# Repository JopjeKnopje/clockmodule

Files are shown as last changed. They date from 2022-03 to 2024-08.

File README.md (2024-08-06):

# Clock Module

The idea behind this project is to have a standalone clock circuit to debug ICs at a very low clock speed.

It is mainly inspired by [Ben Eater's](https://eater.net/8bit/clock) version.

### Features
- Manual pulse Mode.
- Variable frequency clock.
- DC Input Jack 7v - 15v @ approx. 100mA.
- Raw 5v power in for breadboard compatability.
- Lots of LEDs :)

### Parts
- 2x 0.01uF - Ceramic Capacitor
- 2x 4.7uF - Capacitor
- 1x 470uF - Capacitor
- 1x .33uF - Ceramic Capacitor
- 4x .1uF - Ceramic Capacitor
- 1x 1uF - Capacitor
- 1x 1N4007 - Diode
- 4x 5mm LED
- 2x 01x02 Female Pin header
- 1x DC Jack
- 6x 1K - Resistor
- 2x 51K - Resistor
- 2x 10K - Resistor
- 1x 100K - Potentiometer linear
- 2x Button
- 3x NE555P
- 1x L7805
- 1x 7400

### What does it look like
#### KiCad Render
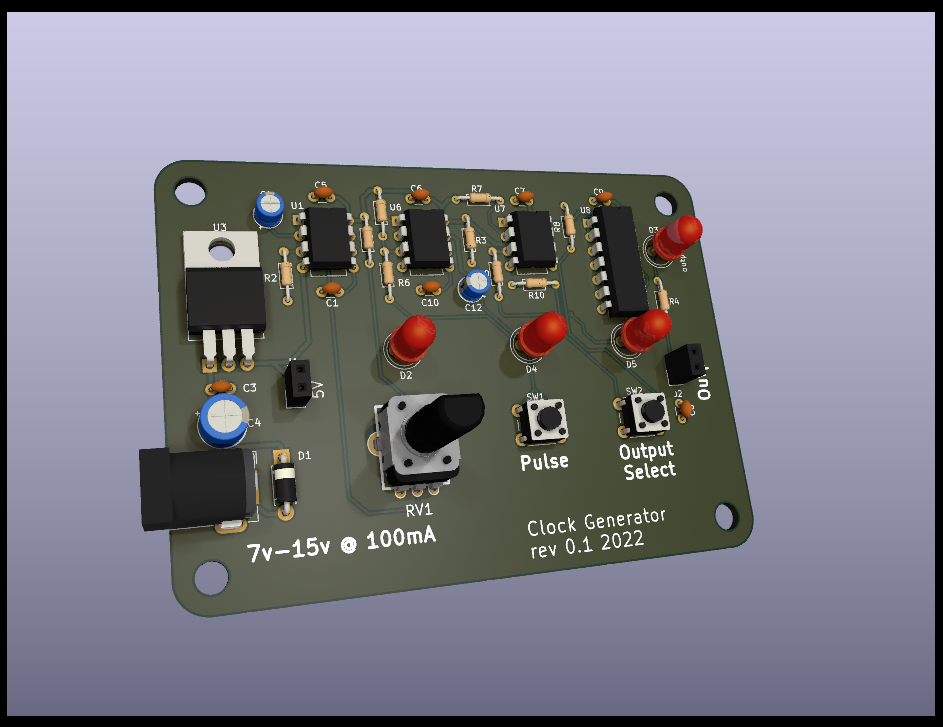
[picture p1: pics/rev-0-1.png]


### Todo
- [ ] Use CMOS ICs for a 5vpp output
- [x] Add partslist
- [ ] Add photos
- [x] Swap silkscreen position of c3 and c4 
- [x] Different footprint for c8

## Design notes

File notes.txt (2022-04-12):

https://www.falstad.com/circuit/circuitjs.html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

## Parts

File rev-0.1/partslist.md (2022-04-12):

- 2x 0.01uF, C
- 2x 4.7uF, C_Polarized
- 1x 470, C_Polarized
- 1x .33uF, C
- 4x .1uF, C
- 1x 1uF, C_Polarized
- 1x 1N4007, D
- 4x LED, LED
- 4x MountingHole, MountingHole
- 1x Vin, Conn_01x02_Female
- 1x Clock output, Conn_01x02_Female
- 1x DC Input, Barrel_Jack_Switch
- 6x 1K, R
- 2x 51K, R
- 2x 10K, R
- 1x 100K, R_Potentiometer
- 2x SW_Push, SW_Push
- 3x NE555P, NE555P
- 1x L7805_J, L7805_J
- 1x 7400, 7400

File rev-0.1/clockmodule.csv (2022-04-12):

Item | Qty | Reference(s) | Value | LibPart | Footprint | Datasheet
 |  | C1 | 0.01uF | Device:C | Capacitor_THT:C_Disc_D3.0mm_W1.6mm_P2.50mm | ~
 |  | C2 | 4.7uF | Device:C_Polarized | Capacitor_THT:CP_Radial_D4.0mm_P1.50mm | ~
 |  | C3 | 470 | Device:C_Polarized | Capacitor_THT:CP_Radial_D6.3mm_P2.50mm | ~
 |  | C4 | .33uF | Device:C | Capacitor_THT:C_Disc_D3.0mm_W1.6mm_P2.50mm | ~
 |  | C5 | .1uF | Device:C | Capacitor_THT:C_Disc_D3.0mm_W1.6mm_P2.50mm | ~
 |  | C6 | .1uF | Device:C | Capacitor_THT:C_Disc_D3.0mm_W1.6mm_P2.50mm | ~
 |  | C7 | .1uF | Device:C | Capacitor_THT:C_Disc_D3.0mm_W1.6mm_P2.50mm | ~
 |  | C8 | 1uF | Device:C_Polarized | Capacitor_THT:C_Disc_D3.0mm_W1.6mm_P2.50mm | ~
 |  | C9 | .1uF | Device:C | Capacitor_THT:C_Disc_D3.0mm_W1.6mm_P2.50mm | ~
 |  | C10 | 0.01uF | Device:C | Capacitor_THT:C_Disc_D3.0mm_W1.6mm_P2.50mm | ~
 |  | C12 | 4.7uF | Device:C_Polarized | Capacitor_THT:CP_Radial_D4.0mm_P1.50mm | ~
 |  | D1 | 1N4007 | Device:D | Diode_THT:D_DO-41_SOD81_P7.62mm_Horizontal | ~
 |  | D2 | LED | Device:LED | LED_THT:LED_D5.0mm | ~
 |  | D3 | LED | Device:LED | LED_THT:LED_D5.0mm | ~
 |  | D4 | LED | Device:LED | LED_THT:LED_D5.0mm | ~
 |  | D5 | LED | Device:LED | LED_THT:LED_D5.0mm | ~
 |  | H1 | MountingHole | Mechanical:MountingHole | MountingHole:MountingHole_4.3mm_M4 | ~
 |  | H2 | MountingHole | Mechanical:MountingHole | MountingHole:MountingHole_4.3mm_M4 | ~
 |  | H3 | MountingHole | Mechanical:MountingHole | MountingHole:MountingHole_4.3mm_M4 | ~
 |  | H4 | MountingHole | Mechanical:MountingHole | MountingHole:MountingHole_4.3mm_M4 | ~
 |  | J1 | Vin | Connector:Conn_01x02_Female | Connector_PinSocket_2.54mm:PinSocket_1x02_P2.54mm_Vertical | ~
 |  | J2 | Clock output | Connector:Conn_01x02_Female | Connector_PinSocket_2.54mm:PinSocket_1x02_P2.54mm_Vertical | ~
 |  | J3 | DC Input | Connector:Barrel_Jack_Switch | Connector_BarrelJack:BarrelJack_GCT_DCJ200-10-A_Horizontal | ~
 |  | R1 | 1K | Device:R | Resistor_THT:R_Axial_DIN0204_L3.6mm_D1.6mm_P7.62mm_Horizontal | ~
 |  | R2 | 1K | Device:R | Resistor_THT:R_Axial_DIN0204_L3.6mm_D1.6mm_P7.62mm_Horizontal | ~
 |  | R3 | 1K | Device:R | Resistor_THT:R_Axial_DIN0204_L3.6mm_D1.6mm_P7.62mm_Horizontal | ~
 |  | R4 | 1K | Device:R | Resistor_THT:R_Axial_DIN0204_L3.6mm_D1.6mm_P7.62mm_Horizontal | ~
 |  | R5 | 51K | Device:R | Resistor_THT:R_Axial_DIN0204_L3.6mm_D1.6mm_P7.62mm_Horizontal | ~
 |  | R6 | 1K | Device:R | Resistor_THT:R_Axial_DIN0204_L3.6mm_D1.6mm_P7.62mm_Horizontal | ~
 |  | R7 | 10K | Device:R | Resistor_THT:R_Axial_DIN0204_L3.6mm_D1.6mm_P7.62mm_Horizontal | ~
 |  | R8 | 10K | Device:R | Resistor_THT:R_Axial_DIN0204_L3.6mm_D1.6mm_P7.62mm_Horizontal | ~
 |  | R9 | 1K | Device:R | Resistor_THT:R_Axial_DIN0204_L3.6mm_D1.6mm_P7.62mm_Horizontal | ~
 |  | R10 | 51K | Device:R | Resistor_THT:R_Axial_DIN0204_L3.6mm_D1.6mm_P7.62mm_Horizontal | ~
 |  | RV1 | 100K | Device:R_Potentiometer | w_pth_resistors:trimmer_alps-rk09k1130ah1 | ~
 |  | SW1 | SW_Push | Switch:SW_Push | Button_Switch_THT:SW_PUSH_6mm_H5mm | ~
 |  | SW2 | SW_Push | Switch:SW_Push | Button_Switch_THT:SW_PUSH_6mm_H5mm | ~
 |  | U1 | NE555P | Timer:NE555P | Package_DIP:DIP-8_W7.62mm | http://www.ti.com/lit/ds/symlink/ne555.pdf
 |  | U3 | L7805_J | joppe:L7805_J | Package_TO_SOT_THT:TO-220-3_Horizontal_TabDown | http://www.st.com/content/ccc/resource/technical/document/datasheet/41/4f/b3/b0/12/d4/47/88/CD00000444.pdf/files/CD00000444.pdf/jcr:content/translations/en.CD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
 |  | U6 | NE555P | Timer:NE555P | Package_DIP:DIP-8_W7.62mm | http://www.ti.com/lit/ds/symlink/ne555.pdf
 |  | U7 | NE555P | Timer:NE555P | Package_DIP:DIP-8_W7.62mm | http://www.ti.com/lit/ds/symlink/ne555.pdf
 |  | U8 | 7400 | 74xx:7400 | Package_DIP:DIP-14_W7.62mm | http://www.ti.com/lit/gpn/sn7400

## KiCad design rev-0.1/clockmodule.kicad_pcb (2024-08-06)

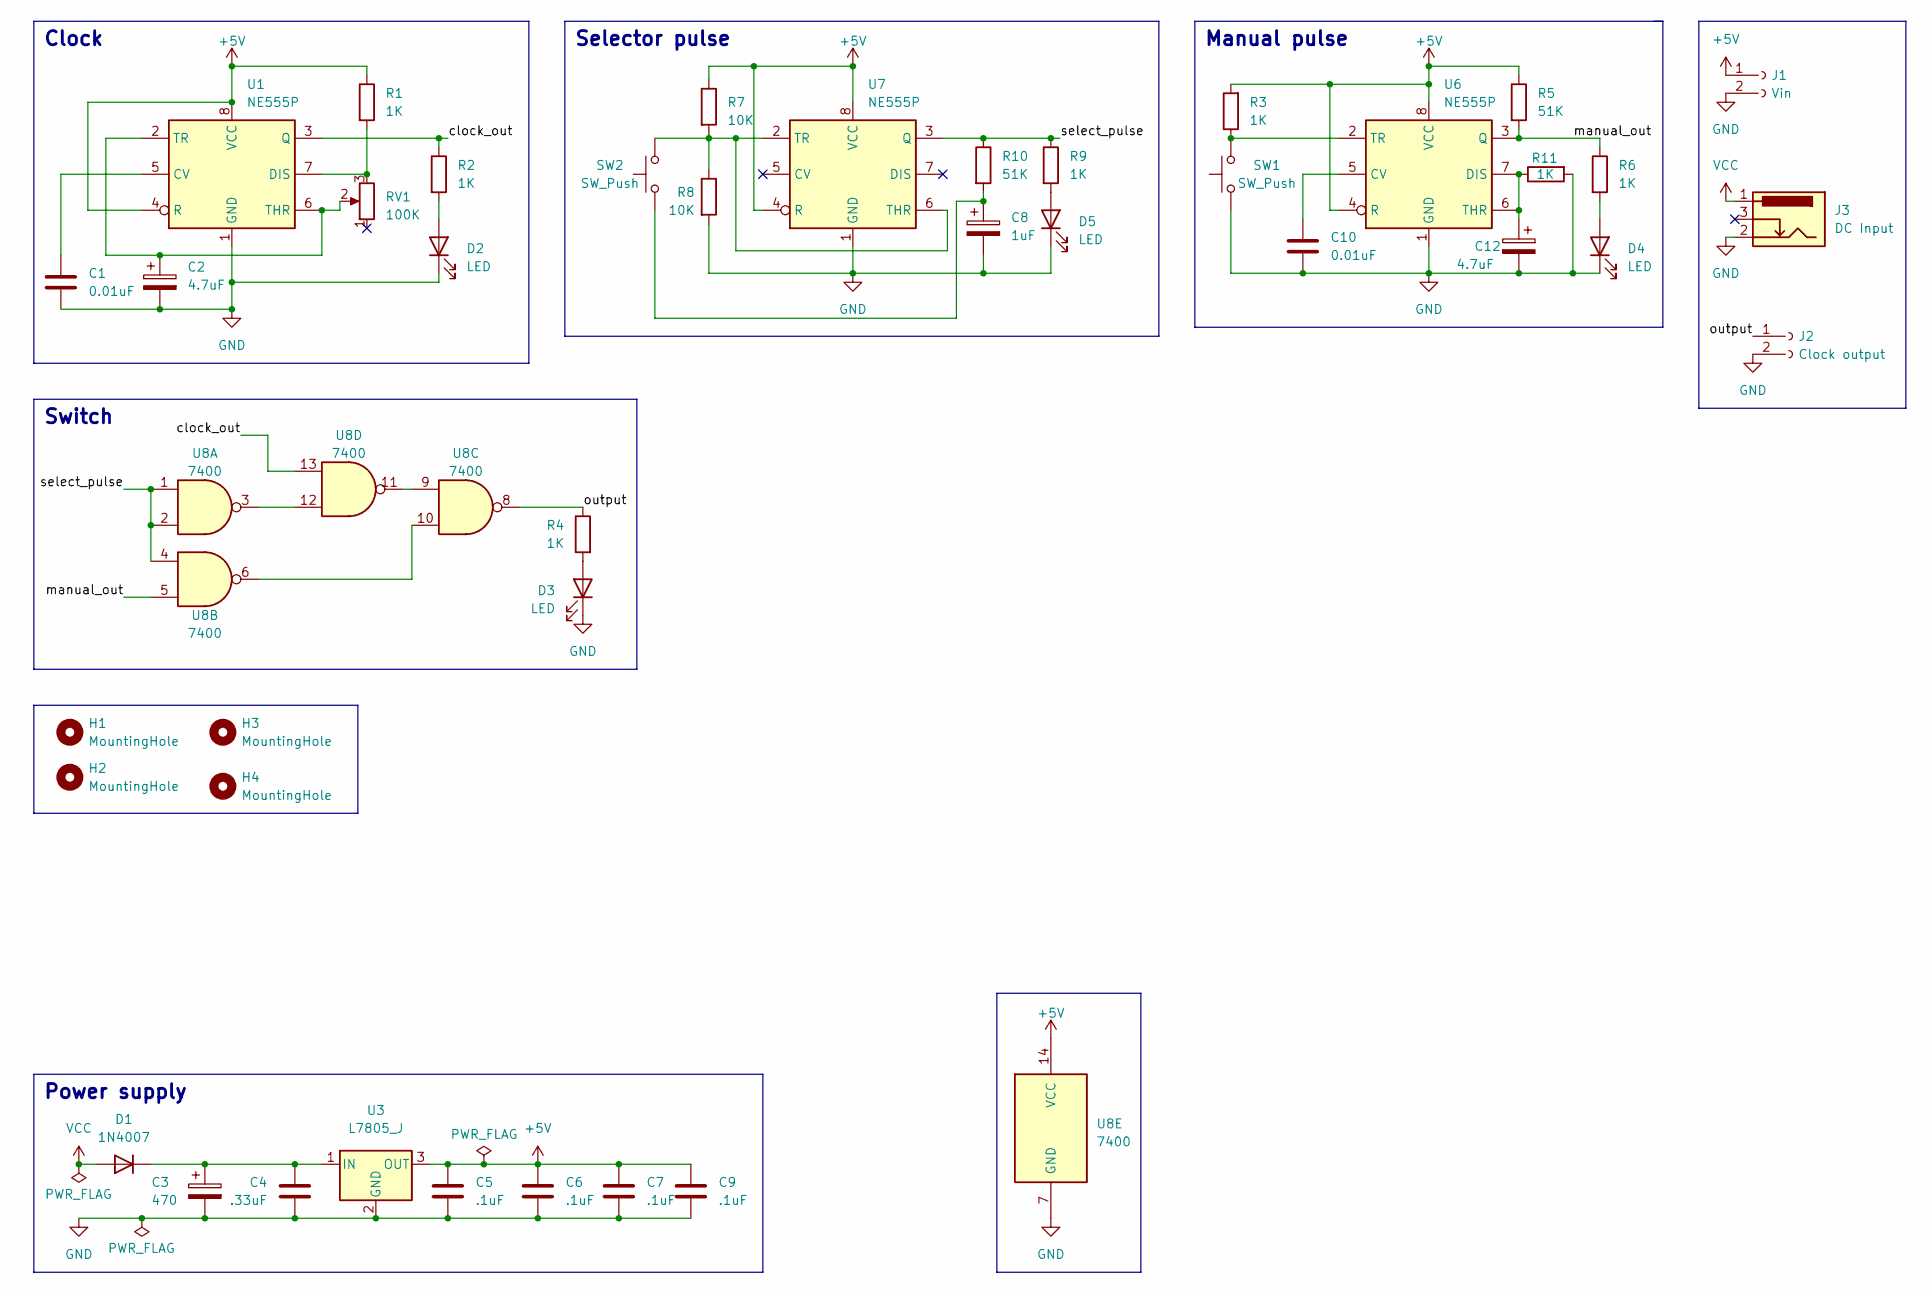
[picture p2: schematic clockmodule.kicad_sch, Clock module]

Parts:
C1, C10: 0.01uF; C_Disc_D3.0mm_W1.6mm_P2.50mm
C2, C12: 4.7uF; CP_Radial_D4.0mm_P1.50mm
C3: 470; CP_Radial_D6.3mm_P2.50mm
C4: .33uF; C_Disc_D3.0mm_W1.6mm_P2.50mm
C5, C6, C7, C9: .1uF; C_Disc_D3.0mm_W1.6mm_P2.50mm
C8: 1uF; CP_Radial_D4.0mm_P1.50mm
D1: 1N4007; D_DO-41_SOD81_P7.62mm_Horizontal
D2, D3, D4, D5: LED; LED_D5.0mm
H1, H2, H3, H4: MountingHole; MountingHole_4.3mm_M4
J1: Vin; PinSocket_1x02_P2.54mm_Vertical
J2: Clock output; PinSocket_1x02_P2.54mm_Vertical
J3: DC Input; BarrelJack_GCT_DCJ200-10-A_Horizontal
R1, R2, R3, R4, R6, R9, R11: 1K; R_Axial_DIN0204_L3.6mm_D1.6mm_P7.62mm_Horizontal
R5, R10: 51K; R_Axial_DIN0204_L3.6mm_D1.6mm_P7.62mm_Horizontal
R7, R8: 10K; R_Axial_DIN0204_L3.6mm_D1.6mm_P7.62mm_Horizontal
RV1: 100K; trimmer_alps-rk09k1130ah1
SW1, SW2: SW_Push; SW_PUSH_6mm_H5mm
U1, U6, U7: NE555P; DIP-8_W7.62mm
U3: L7805_J; TO-220-3_Horizontal_TabDown
U8: 7400; DIP-14_W7.62mm

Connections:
+5V: C5.1, C6.1, C7.1, C9.1, J1.1, R1.1, R3.2, R5.1, R7.1, U1.4 (R), U1.8 (VCC), U3.3 (OUT), U6.4 (R), U6.8 (VCC), U7.4 (R), U7.8 (VCC), U8.14 (VCC)
/clock_out: R2.1, U1.3 (Q), U8.13
/manual_out: R5.2, R6.1, U6.3 (Q), U8.5
/output: J2.1, R4.1, U8.8
/select_pulse: R9.1, R10.1, U7.3 (Q), U8.1, U8.2, U8.4
GND: C1.1, C2.2, C3.2, C4.1, C5.2, C6.2, C7.2, C8.2, C9.2, C10.2, C12.2, D2.1 (K), D3.1 (K), D4.1 (K), D5.1 (K), J1.2, J2.2, J3.2, R8.2, R11.2, SW1.2, U1.1 (GND), U3.2 (GND), U6.1 (GND), U7.1 (GND), U8.7 (GND)
unnamed: C8.1, R10.2, SW2.2
unnamed: C3.1, C4.2, D1.1 (K), U3.1 (IN)
unnamed: D2.2 (A), R2.2
unnamed: D3.2 (A), R4.2
unnamed: D4.2 (A), R6.2
unnamed: D5.2 (A), R9.2
unnamed: C1.2, U1.5 (CV)
unnamed: R1.2, RV1.3, U1.7 (DIS)
unnamed: C2.1, RV1.2, U1.2 (TR), U1.6 (THR)
unnamed: C10.1, U6.5 (CV)
unnamed: C12.1, R11.1, U6.6 (THR), U6.7 (DIS)
unnamed: R3.1, SW1.1, U6.2 (TR)
unnamed: R7.2, R8.1, SW2.1, U7.2 (TR), U7.6 (THR)
unnamed: U8.6, U8.10
unnamed: U8.9, U8.11
unnamed: U8.3, U8.12
VCC: D1.2 (A), J3.1

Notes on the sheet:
Power supply
Selector pulse
Switch
Clock
Manual pulse

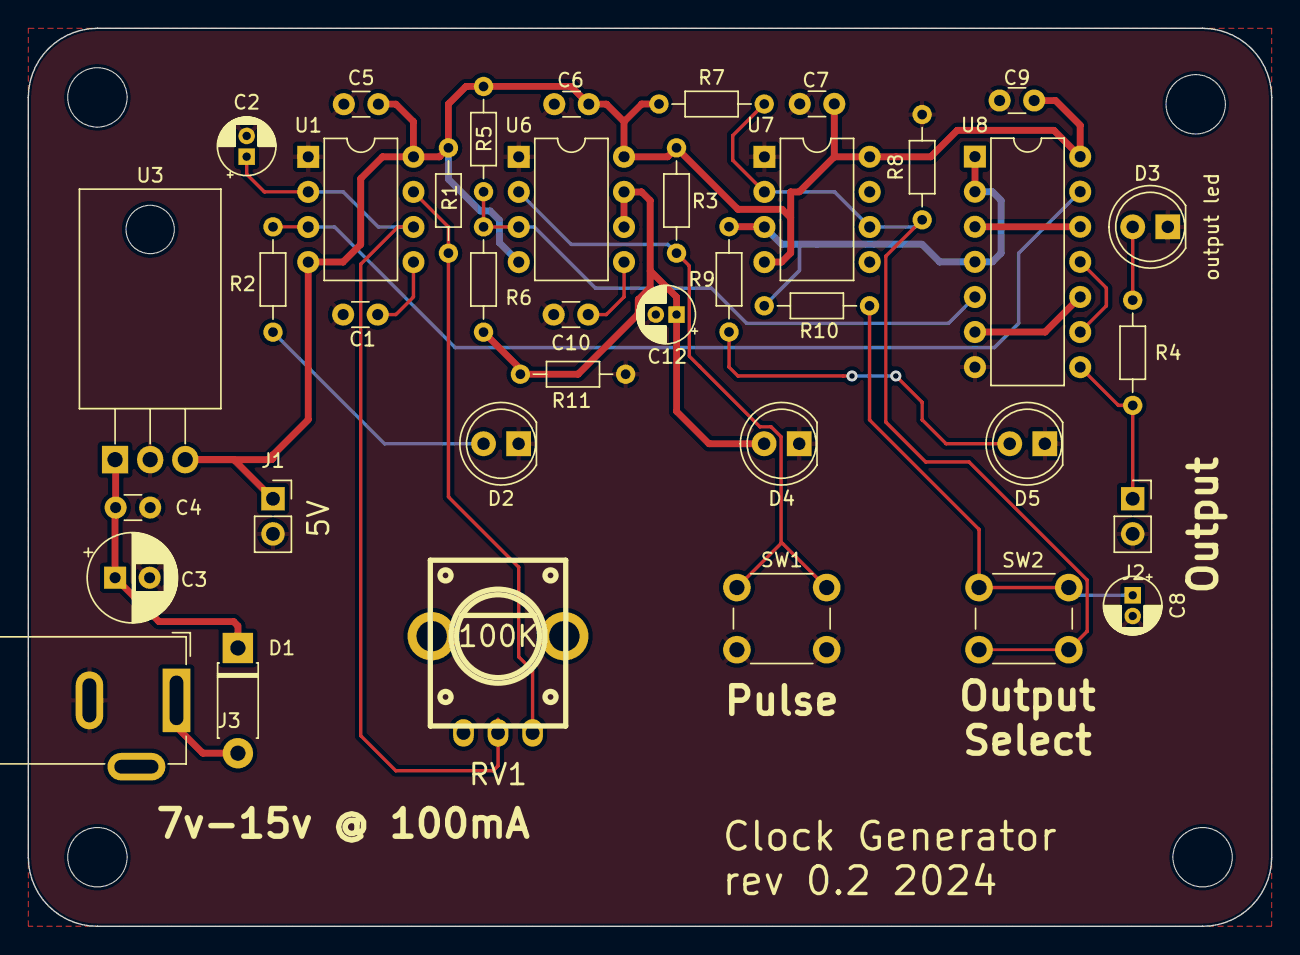
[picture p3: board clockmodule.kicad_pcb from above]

Board: 2 copper layers, 90.0 x 65.0 mm, 42 parts (0 on the bottom side), 23 nets.

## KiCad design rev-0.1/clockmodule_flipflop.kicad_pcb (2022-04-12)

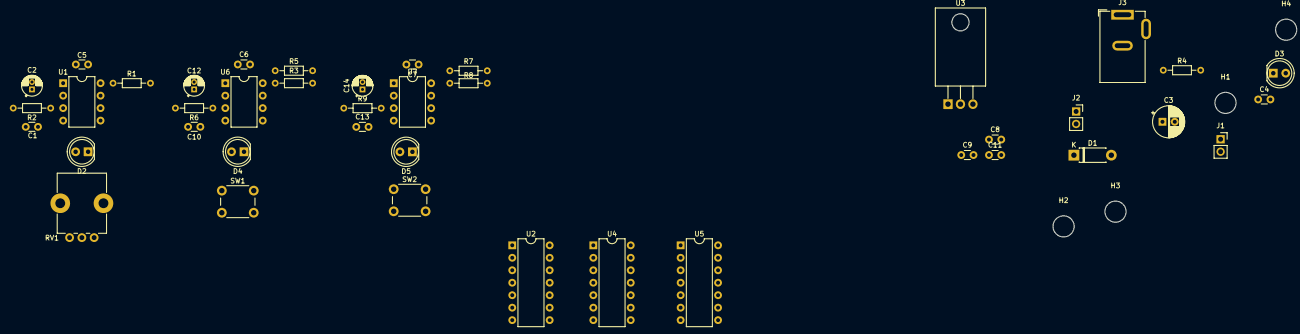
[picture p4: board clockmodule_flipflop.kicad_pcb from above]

Board: 2 copper layers, 45 parts (0 on the bottom side), 25 nets, no tracks yet.

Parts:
C1, C10, C13: 0.01uF; C_Disc_D3.0mm_W1.6mm_P2.50mm
C2, C12, C14: 4.7uF; CP_Radial_D4.0mm_P1.50mm
C3: 470; CP_Radial_D6.3mm_P2.50mm
C4: .33uF; C_Disc_D3.0mm_W1.6mm_P2.50mm
C5, C6, C7, C8, C9, C11: .1uF; C_Disc_D3.0mm_W1.6mm_P2.50mm
D1: 1N4007; D_DO-41_SOD81_P7.62mm_Horizontal
D2, D3, D4, D5: LED; LED_D5.0mm
H1, H2, H3, H4: MountingHole; MountingHole_4.3mm_M4
J1, J2: Conn_01x02_Female; PinSocket_1x02_P2.54mm_Vertical
J3: Barrel_Jack_Switch; BarrelJack_GCT_DCJ200-10-A_Horizontal
R1, R2, R3, R4, R6, R7, R9: 1K; R_Axial_DIN0204_L3.6mm_D1.6mm_P7.62mm_Horizontal
R5, R8: 51K; R_Axial_DIN0204_L3.6mm_D1.6mm_P7.62mm_Horizontal
RV1: 100K; Potentiometer_Alps_RK09K_Single_Vertical
SW1, SW2: SW_Push; SW_PUSH_6mm_H5mm
U1, U6, U7: NE555P; DIP-8_W7.62mm
U2: 74LS107; DIP-14_W7.62mm
U3: L7805_J; TO-220-3_Horizontal_TabDown
U4: 74LS08; DIP-14_W7.62mm
U5: 74HC86; DIP-14_W7.62mm

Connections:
+5V: C5.1, C6.1, C7.1, C8.1, C9.1, C11.1, J1.1, R1.1, R3.2, R5.1, R7.2, R8.1, U1.4 (R), U1.8 (VCC), U2.1 (J), U2.4 (K), U2.13 (~R), U2.14 (VCC), U3.3 (OUT), U4.14 (VCC), U5.14 (VCC), U6.4 (R), U6.8 (VCC), U7.4 (R), U7.8 (VCC)
/clock_out: R2.1, U1.3 (Q), U4.2
/manual_out: R5.2, R6.1, U4.4, U6.3 (Q)
/output: D3.2 (A), J2.1, U5.3
/select_pulse: R8.2, R9.1, U2.12 (C), U7.3 (Q)
GND: C1.1, C2.2, C3.2, C4.1, C5.2, C6.2, C7.2, C8.2, C9.2, C10.2, C11.2, C12.2, C13.2, C14.2, D2.1 (K), D4.1 (K), D5.1 (K), J1.2, J2.2, J3.2, R4.2, SW1.2, SW2.2, U1.1 (GND), U2.7 (GND), U3.2 (GND), U4.7 (GND), U5.7 (GND), U6.1 (GND), U7.1 (GND)
unnamed: C3.1, C4.2, D1.1 (K), U3.1 (IN)
unnamed: D2.2 (A), R2.2
unnamed: D3.1 (K), R4.1
unnamed: D4.2 (A), R6.2
unnamed: D5.2 (A), R9.2
unnamed: C1.2, U1.5 (CV)
unnamed: R1.2, RV1.1, U1.7 (DIS)
unnamed: C2.1, RV1.2, U1.2 (TR), U1.6 (THR)
unnamed: U2.3 (Q), U4.5
unnamed: U2.2 (~Q), U4.1
unnamed: U4.3, U5.2
unnamed: U4.6, U5.1
unnamed: C10.1, U6.5 (CV)
unnamed: C12.1, U6.6 (THR), U6.7 (DIS)
unnamed: R3.1, SW1.1, U6.2 (TR)
unnamed: C13.1, U7.5 (CV)
unnamed: C14.1, U7.6 (THR), U7.7 (DIS)
unnamed: R7.1, SW2.1, U7.2 (TR)
VCC: D1.2 (A), J3.1

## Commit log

2022-03-30 added bomreader
    [clockmodule.csv]
2022-04-12 moved to rev-.1 folder
    [clockmodule-B_Cu.gbl, clockmodule-B_Mask.gbs, clockmodule-B_Paste.gbp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]
2024-08-06 Swapped C4 and C3 silkscreen text
    [clockmodule.kicad_pcb, clockmodule.kicad_sch]
2024-08-06 Moved `R11`
    [clockmodule.kicad_pcb, clockmodule.kicad_sch]
2024-08-06 Change `C8` footprint
    [clockmodule.kicad_pcb, clockmodule.kicad_sch]
